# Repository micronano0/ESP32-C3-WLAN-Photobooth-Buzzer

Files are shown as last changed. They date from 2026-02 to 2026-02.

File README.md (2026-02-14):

# Buzzer

Der **Buzzer** dient dazu, Bilder auf einer Fotobox auszulösen.  
Getestet mit **Photobooth 4.99** und **dslrBooth**.

---

## Funktionen

- **HTTP-Befehl** an einen Webserver senden  
- **MQTT-String** an einen Broker senden (optional)  

---

## Installation & Inbetriebnahme

1. **Buzzer einschalten** → startet einen **Access Point** (`Buzzer`).
2. Mit dem Handy verbinden und die **Weboberfläche** öffnen.
3. WLAN auswählen, mit dem sich der Buzzer verbinden soll
4. statische IP und Gateway eingeben.
5. HTTP-Befehl für den Webserver eingeben.
6. Optional: MQTT aktivieren und Broker-Adresse angeben.
7. Konfiguration speichern → Buzzer startet neu und verbindet sich automatisch mit dem WLAN.

---

## Statusanzeigen (LED)

| Status | Bedeutung |
|---|---|
| Blaue LED dauerhaft an | Buzzer erfolgreich im WLAN angemeldet |
| Blaue LED blinkt | WLAN-Verbindung fehlgeschlagen → Access Point aktiv |
| Blaue LED leuchtet, nicht blinkt | Buzzer im WLAN, aber z. B. mqtt fehler |
| 1x Piep | http Befehl erfolgreich gesendet |
| 2x Piep | http Befehl erfolglos |

---

## Zugriff auf den Access Point

Wenn Änderungen nötig sind:

1. Buzzer ausschalten  
2. Buzzerknopf gedrückt halten  
3. Buzzer einschalten
4. blaue LED blinkt  
5. Mit dem Handy wieder verbinden → Weboberfläche aufrufen → Konfiguration ändern

---

## Verwendung / Auslösen

Drücke den **roten Knopf**, dann passiert Folgendes:

| Situation | Signal |
|---|---|
| HTTP-Befehl erfolgreich gesendet | 1x Piepton |
| Webserver nicht erreichbar | 2x Piepton |
| MQTT aktiviert & Broker erreichbar | Blaue LED blinkt 1x |
| MQTT aktiviert & Broker nicht erreichbar | Blaue LED leuchtet dauerhaft |

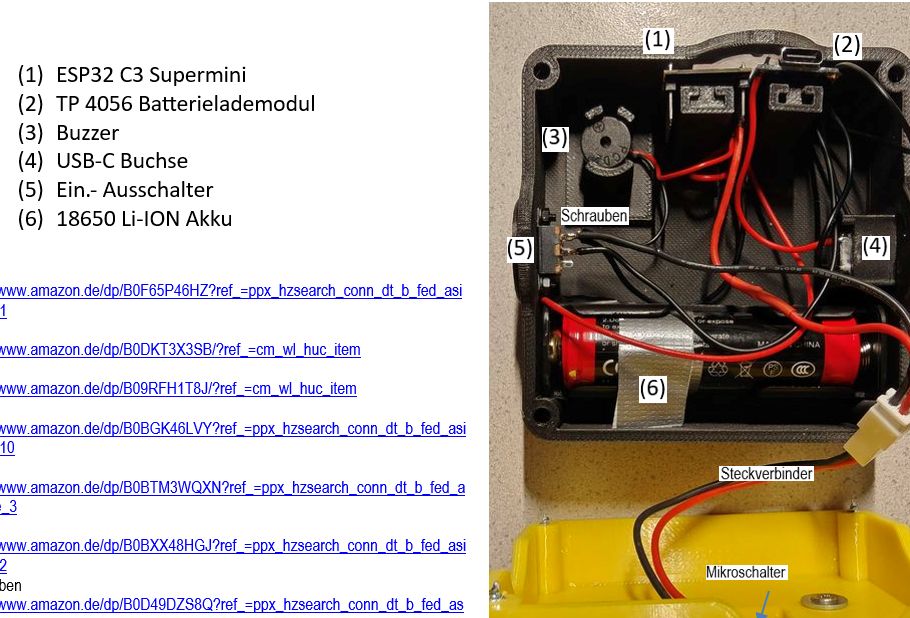
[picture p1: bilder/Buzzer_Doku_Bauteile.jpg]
Buzzer_elektronik_fertig


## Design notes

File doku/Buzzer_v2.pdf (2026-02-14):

### Buzzer

Ich verwende den Buzzer um Bilder auf der Fotobox auszulösen. (getestet wurde Photobooth 4.99 und dslrBooth)

Bei der 1. Inbetriebnahme macht der Buzzer einen AccessPoint auf („Buzzer“) über den man sich mit dem Handy verbinden kann. Über eine Weboberfläche kann man das WLAN auswählen mit dem sich der Buzzer über eine statische IP verbinden soll.

Weiters gibt man den http Befehl ein, welcher an den Webserver gesendet werden soll.

Zusätzlich kann man mqtt aktivieren (wer’s braucht).

Wird die Eingabe gespeichert, dann startet der Buzzer neu und verbindet sich automatisch mit dem eingegebenen WLAN.
Die blaue LED leuchtet durchgehend, wenn sich der Buzzer im WLAN anmelden konnte.
Wurde aber zB eine falsche statische IP vorgegeben, dann ist der Buzzer zwar angemeldet, kann aber nichts machen.

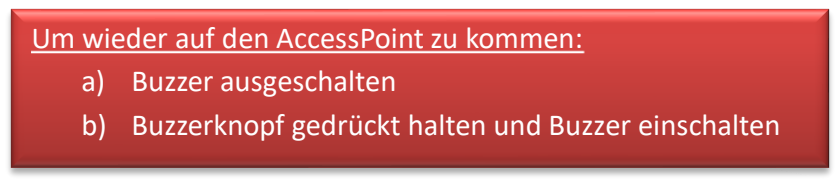
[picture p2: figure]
a) Buzzer ausgeschalten

Handy wieder mit AP verbinden, Webseite aufmachen, Konfiguration ändern.

Konnte sich der Buzzer nicht mit dem WLAN verbinden, dann startet der AccessPoint automatisch, die blau LED blinkt.

Wenn alles richtig konfiguriert ist und man den roten Knopf drückt, dann:
a) Befehl konnte erfolgreich zum Webserver gesendet werden => 1x Piep.
b) Webserver nicht erreichbar => 2x Piep.
c) Mqtt aktiviert und Broker erreichbar => blaue LED blink 1x
d) Mqtt aktiviert und Broker nicht erreichbar => blaue LED bleibt leuchtend (kein blink)

Um wieder auf den AccessPoint zu kommen:

b) Buzzerknopf gedrückt halten und Buzzer einschalten a) einen http Befehl an einen Webserver senden
b) einen mqtt String an einen Broker senden

### Buzzer Menü

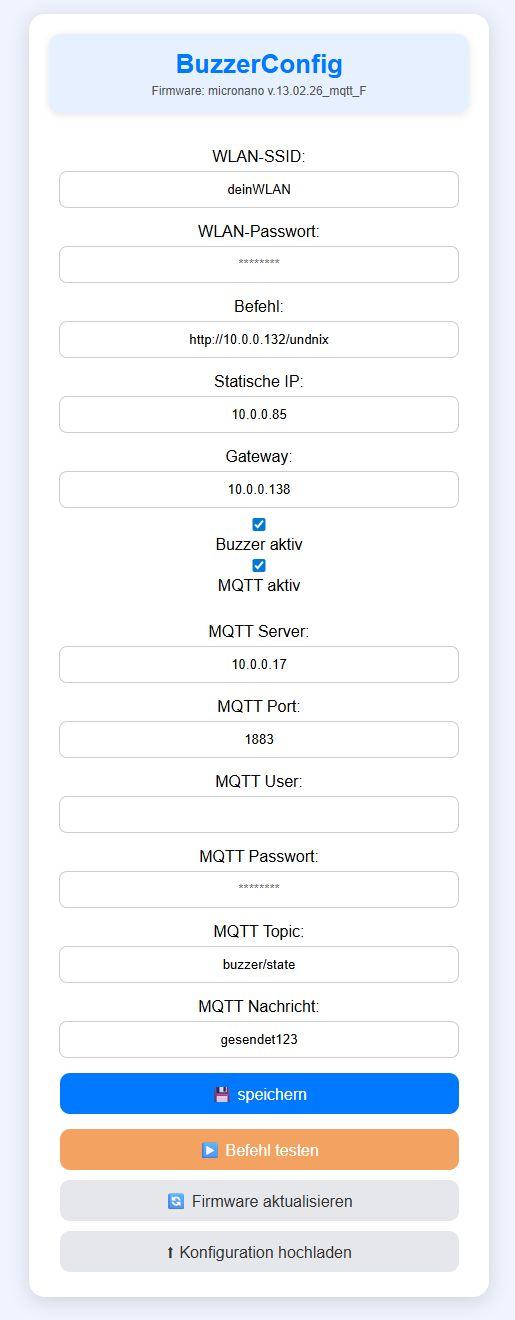
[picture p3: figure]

Firmware aktualisieren: | falls ein Firmware Update zur Verfügung steht
Konfiguration hochladen: | config.json File mit Editor ändern/anpassen und hochladen

### Buzzer Hardware

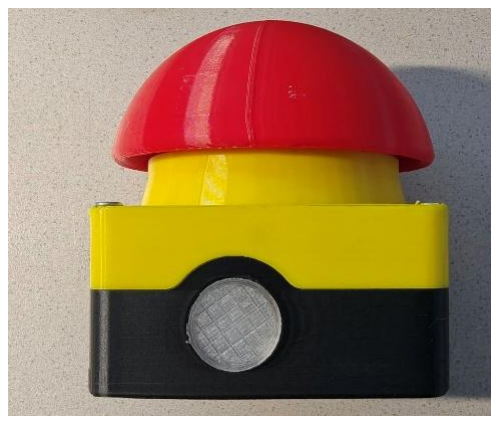
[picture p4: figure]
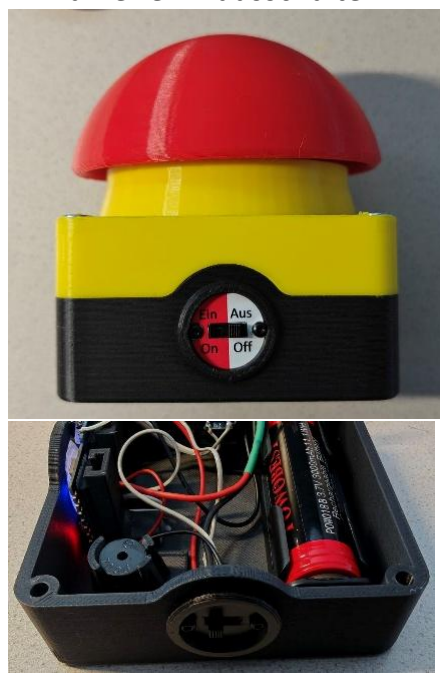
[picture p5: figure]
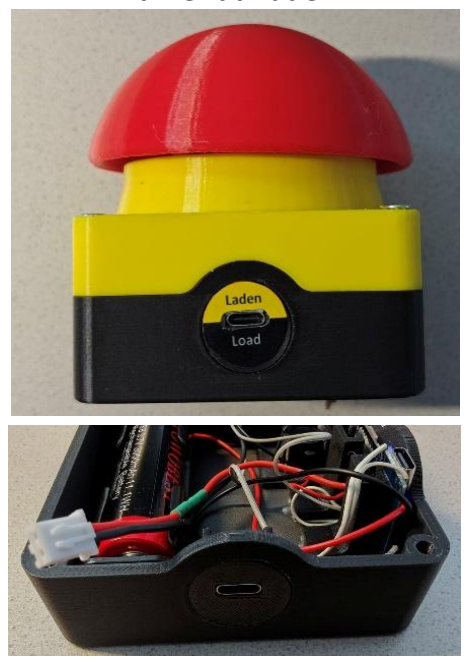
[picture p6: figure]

Buzzer ein.- ausschalten | Buzzer aufladen | Buzzer LED Status

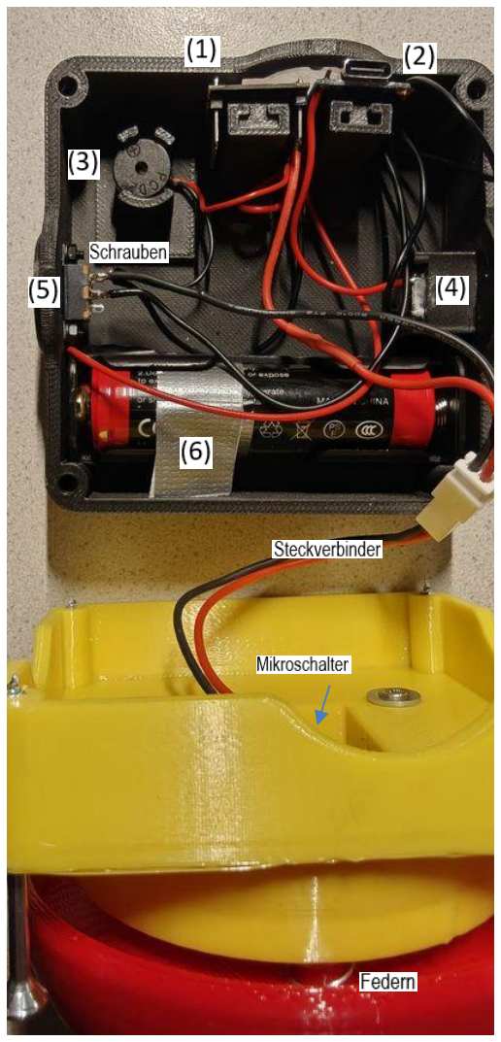
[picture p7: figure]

(1) ESP32 C3 Supermini
(2) TP 4056 Batterielademodul
(3) Buzzer
(4) USB-C Buchse
(5) Ein.- Ausschalter
(6) 18650 Li-ION Akku

(1)
https://www.amazon.de/dp/B0F65P46HZ?ref_=ppx_hzsearch_conn_dt_b_fed_asin_title_1 (https://www.amazon.de/dp/B0F65P46HZ?ref_=ppx_hzsearch_conn_dt_b_fed_asin_title_1)
(2)
https://www.amazon.de/dp/B0DKT3X3SB/?ref_=cm_wl_huc_item
(3)
https://www.amazon.de/dp/B09RFH1T8J/?ref_=cm_wl_huc_item
(4)
https://www.amazon.de/dp/B0BGK46LVY?ref_=ppx_hzsearch_conn_dt_b_fed_asin_title_10 (https://www.amazon.de/dp/B0BGK46LVY?ref_=ppx_hzsearch_conn_dt_b_fed_asin_title_10)
(5)
https://www.amazon.de/dp/B0BTM3WQXN?ref_=ppx_hzsearch_conn_dt_b_fed_asin_title_3 (https://www.amazon.de/dp/B0BTM3WQXN?ref_=ppx_hzsearch_conn_dt_b_fed_asin_title_3)
(6)
https://www.amazon.de/dp/B0BXX48HGJ?ref_=ppx_hzsearch_conn_dt_b_fed_asin_title_2 (https://www.amazon.de/dp/B0BXX48HGJ?ref_=ppx_hzsearch_conn_dt_b_fed_asin_title_2)
Schrauben
https://www.amazon.de/dp/B0D49DZS8Q?ref_=ppx_hzsearch_conn_dt_b_fed_asin_title_1 (https://www.amazon.de/dp/B0D49DZS8Q?ref_=ppx_hzsearch_conn_dt_b_fed_asin_title_1)
Steckverbinder
https://www.amazon.de/dp/B07QMMC4WZ?ref_=ppx_hzsearch_conn_dt_b_fed_asin_title_33 (https://www.amazon.de/dp/B07QMMC4WZ?ref_=ppx_hzsearch_conn_dt_b_fed_asin_title_33)
Mikroschalter
https://www.amazon.de/dp/B07YDFH7H3?ref_=ppx_hzsearch_conn_dt_b_fed_asin_title_1 (https://www.amazon.de/dp/B07YDFH7H3?ref_=ppx_hzsearch_conn_dt_b_fed_asin_title_1)
Federn
https://www.amazon.de/dp/B07WFPPXXX?ref_=ppx_hzsearch_conn_dt_b_fed_asin_title_1 (https://www.amazon.de/dp/B07WFPPXXX?ref_=ppx_hzsearch_conn_dt_b_fed_asin_title_1)

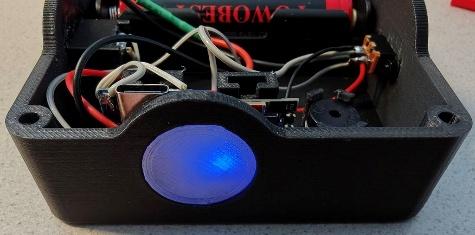
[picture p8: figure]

### MQTT

Windowsprogramme:
a) mosquitto
b) Mqtt Box (AppStore)
1) Terminal als Admin
2) In mosquitto Verzeichnis wechseln: | cd "C:\Program Files\mosquitto"
3) Starte mosquitto im Verzeichnis: | net start mosquitto
4) 2. Terminal check ob 1883 da ist: | netstat -a
5) IP vom PC abfragen: | ipconfig

Einen Testbefehl absenden: .\mosquitto_pub -t buzzer/state -m "ON"

mosquitto.conf:
listener 1883 0.0.0.0
allow_anonymous true
bind_address „IP vom PC“

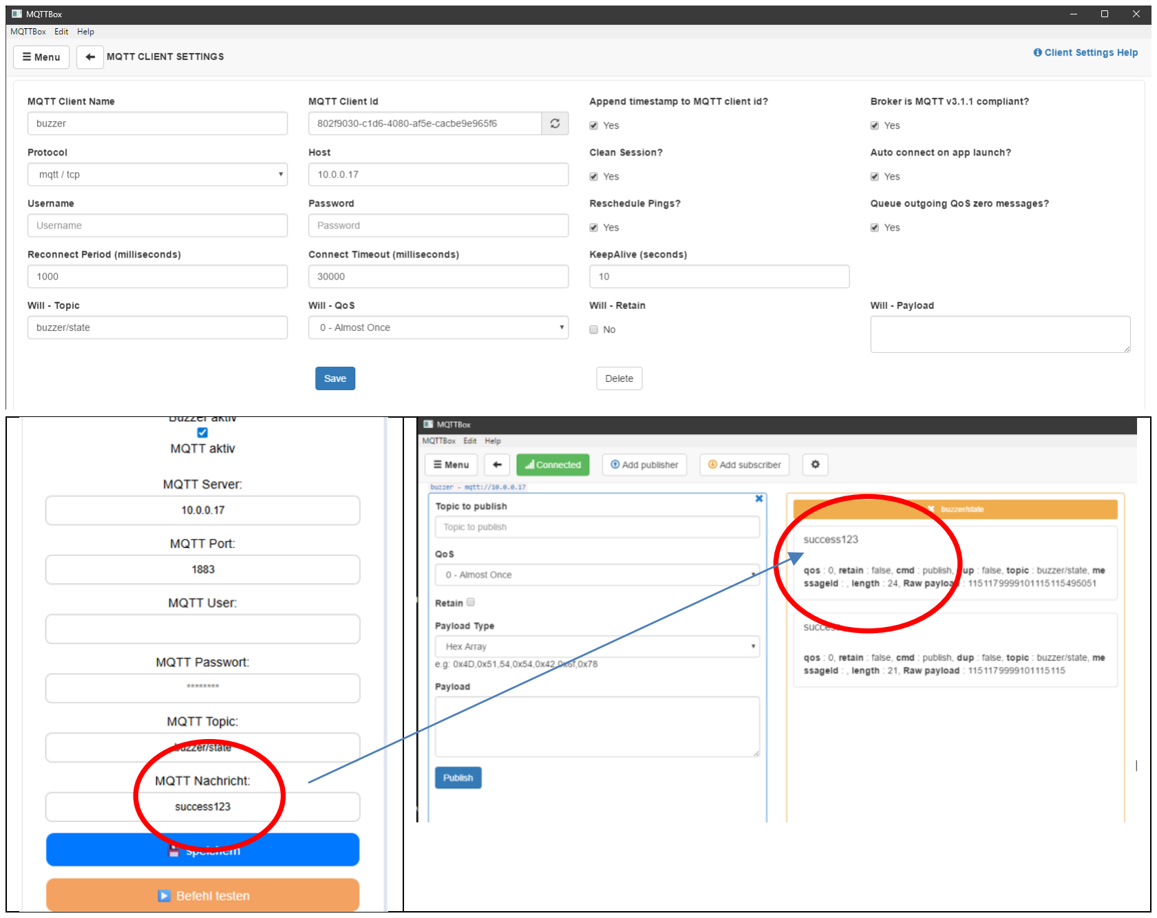
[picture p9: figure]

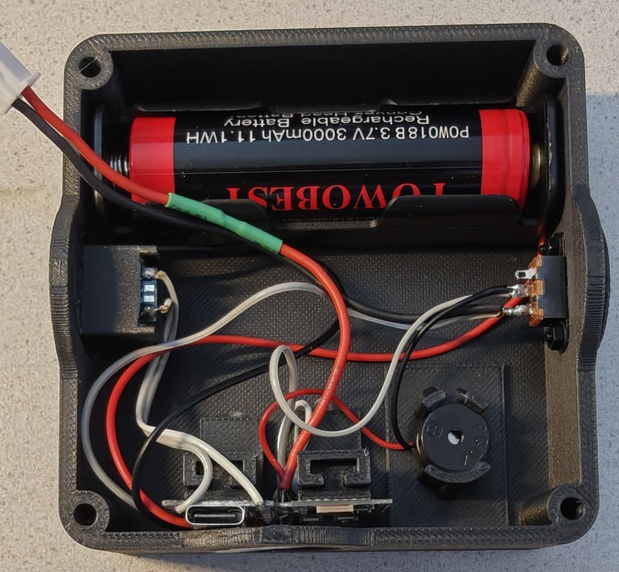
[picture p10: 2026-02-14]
bilder/Buzzer_elektronik.jpg

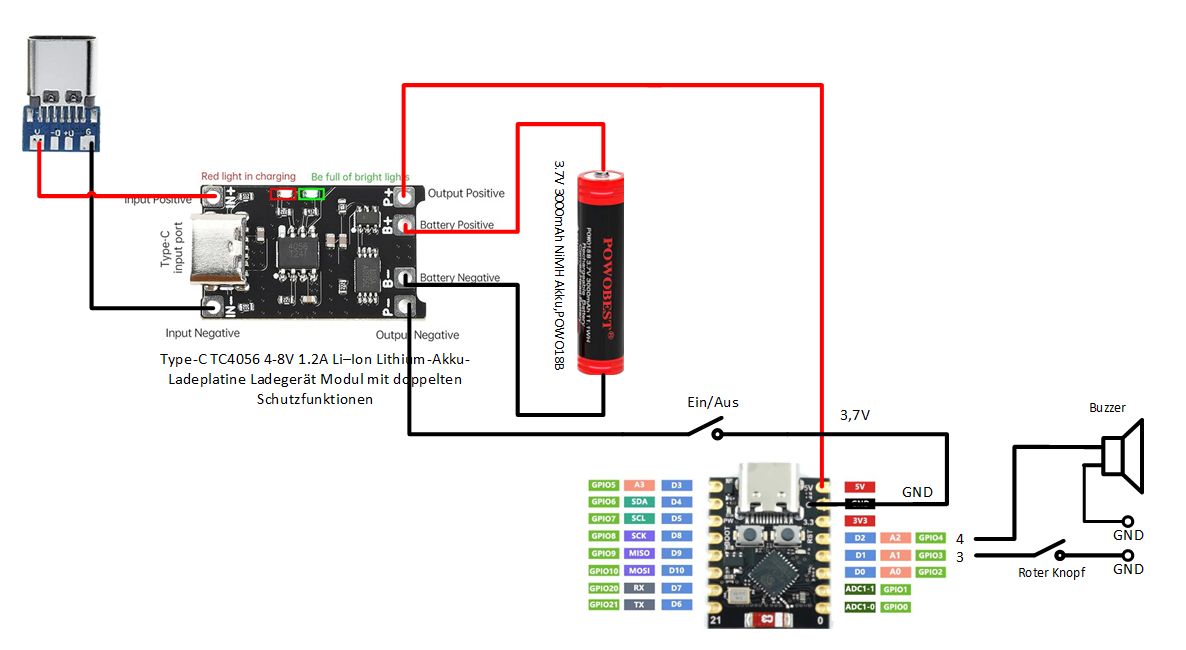
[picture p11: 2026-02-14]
bilder/Buzzer_v2_SchaltPlan.jpg

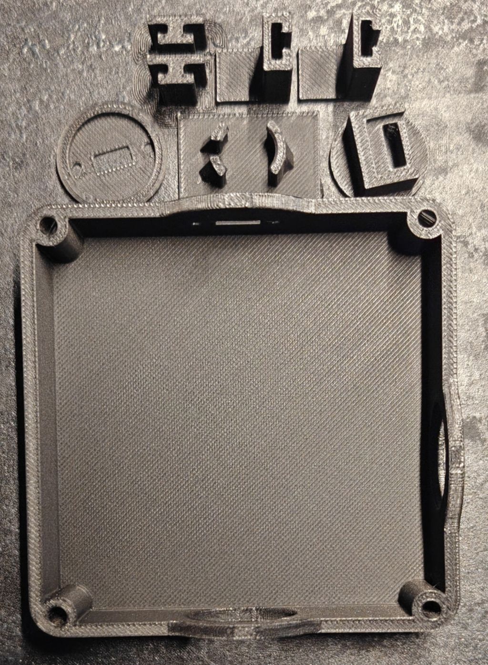
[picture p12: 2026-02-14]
bilder/Buzzer_3D_Druck2.jpg

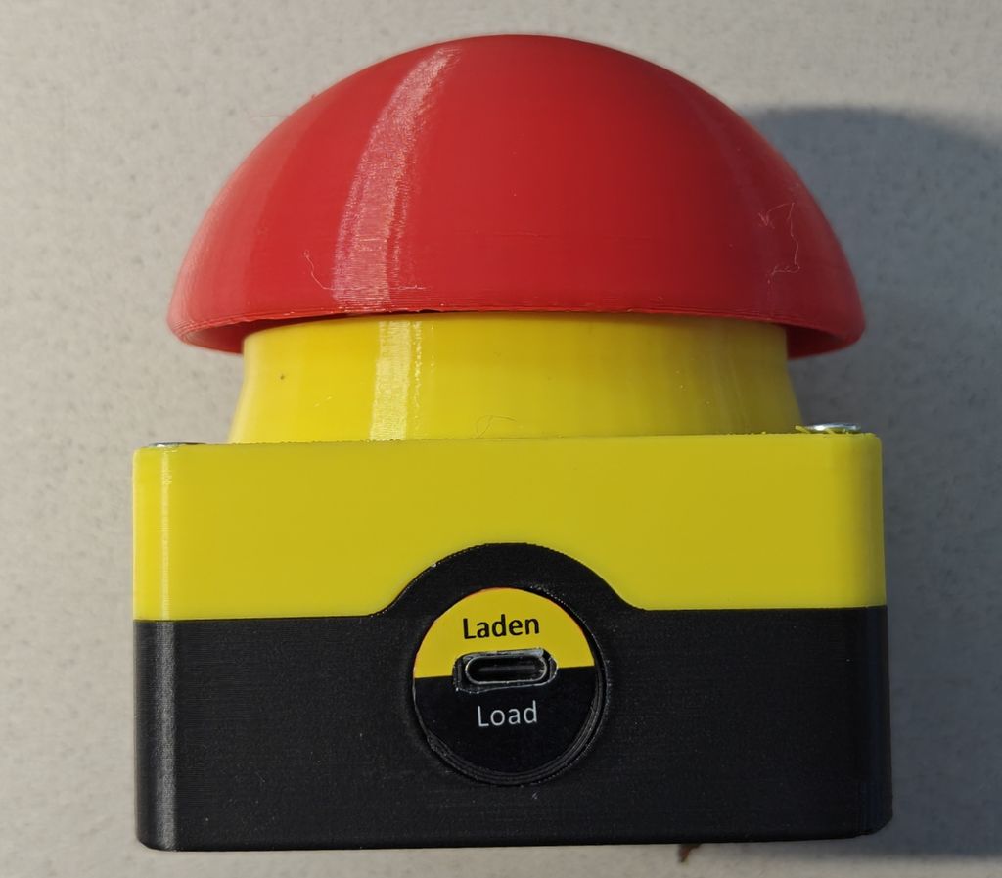
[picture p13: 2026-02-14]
bilder/Buzzer_laden.jpg

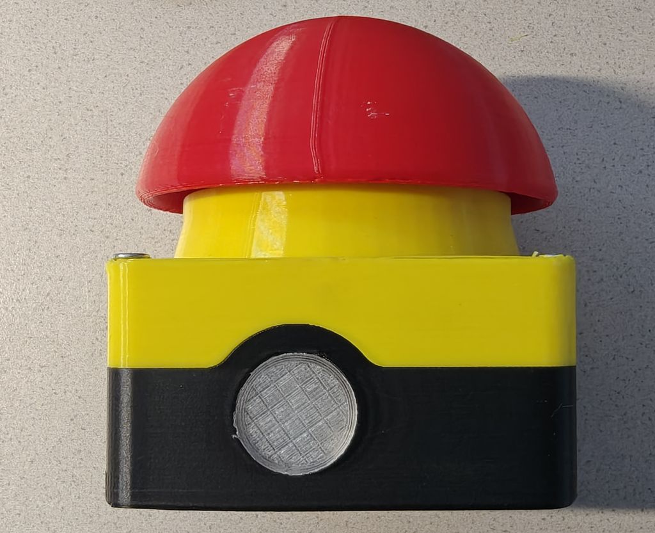
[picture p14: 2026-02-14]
bilder/Buzzer_display.jpg

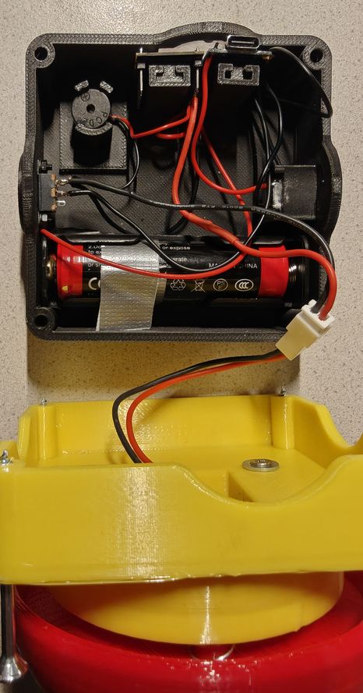
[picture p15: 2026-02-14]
bilder/Buzzer_elektronik_fertig.jpg

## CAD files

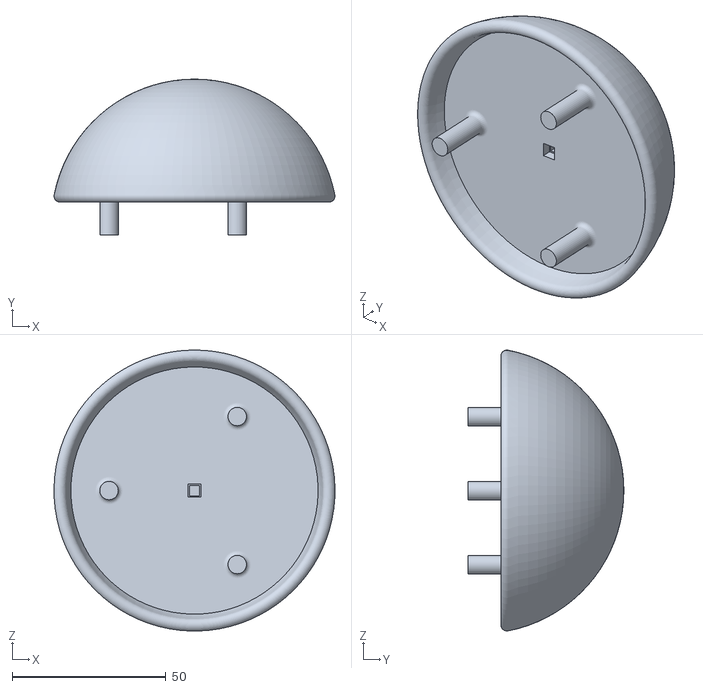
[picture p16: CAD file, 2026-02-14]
stl/BuzzerKnopf.STL
91.4 x 50.6 x 91.3

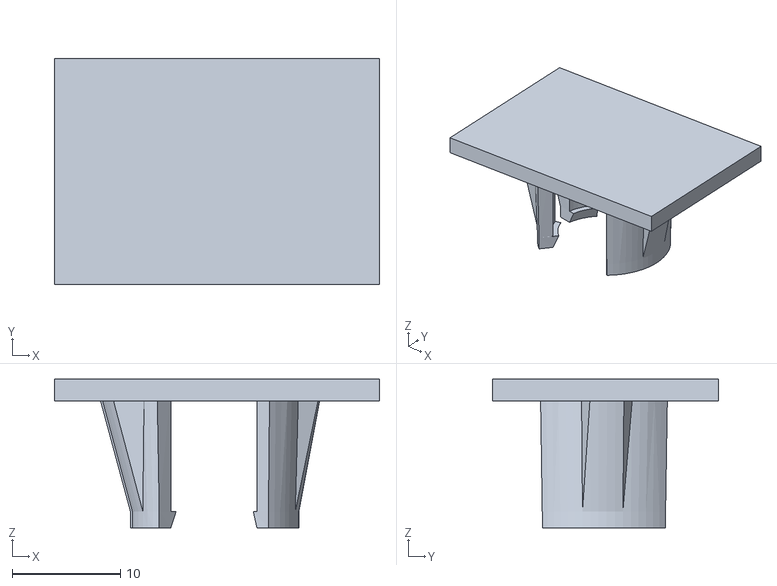
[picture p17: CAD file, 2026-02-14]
stl/buzzer_halterung.stl
30.1 x 21.0 x 13.8

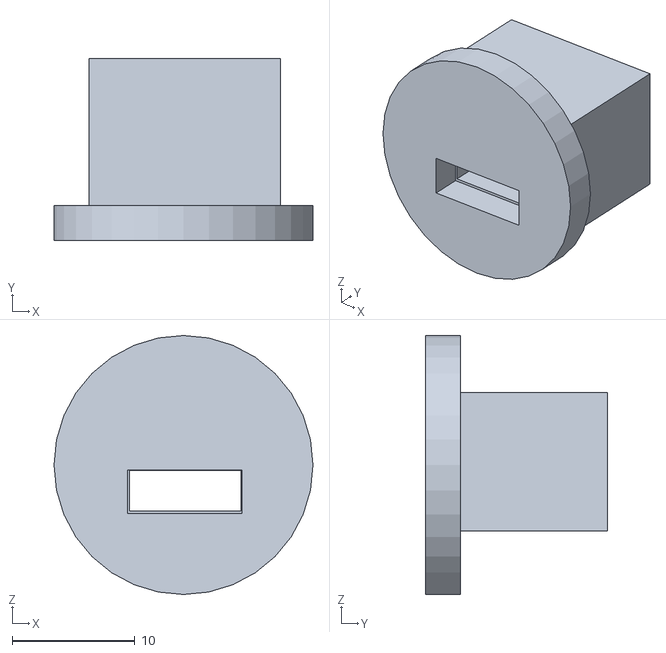
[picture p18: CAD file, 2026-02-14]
stl/usb_c_deckel_2.stl
21.1 x 14.9 x 21.1

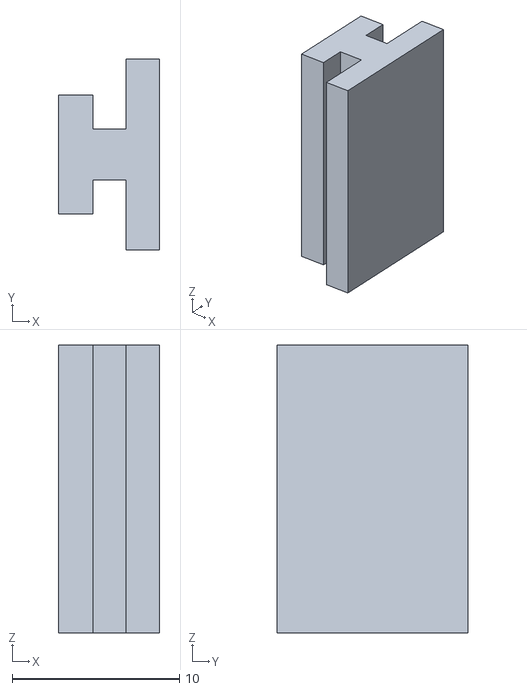
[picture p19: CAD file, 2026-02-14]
stl/Platinenhalter_T1.stl
6.01 x 11.4 x 17.2

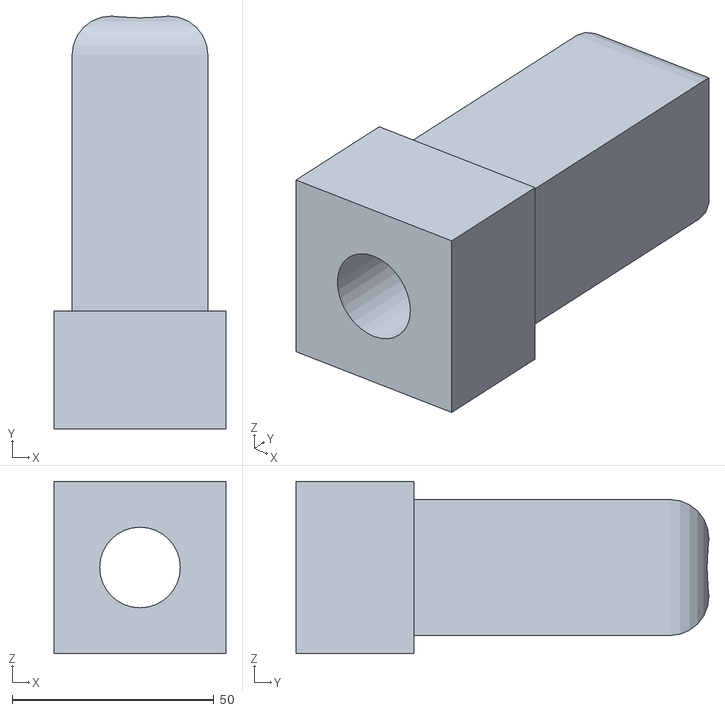
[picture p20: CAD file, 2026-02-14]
stl/buzzer_red_(1)_taster_schraubenhalter.stl
42.7 x 102.4 x 42.8

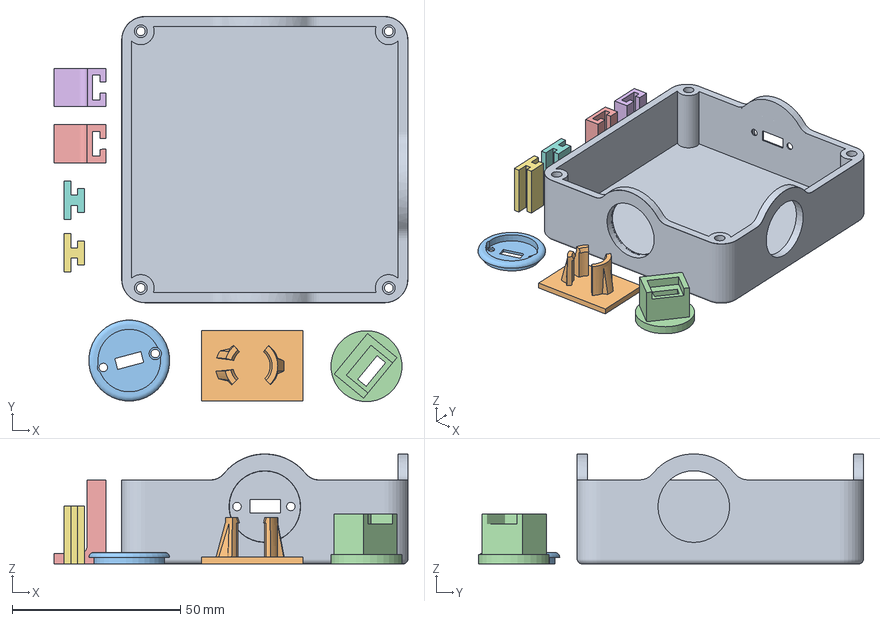
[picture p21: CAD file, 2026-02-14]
stl/gehaeuse.3mf
105.2 x 114.4 x 32.7 mm
BuzzerBoden.STL
buzzer_halterung.stl
schalter_deckel_2.stl
usb_c_deckel_2.stl
Platinenhalter_T2.stl x 2
Platinenhalter_T1.stl x 2

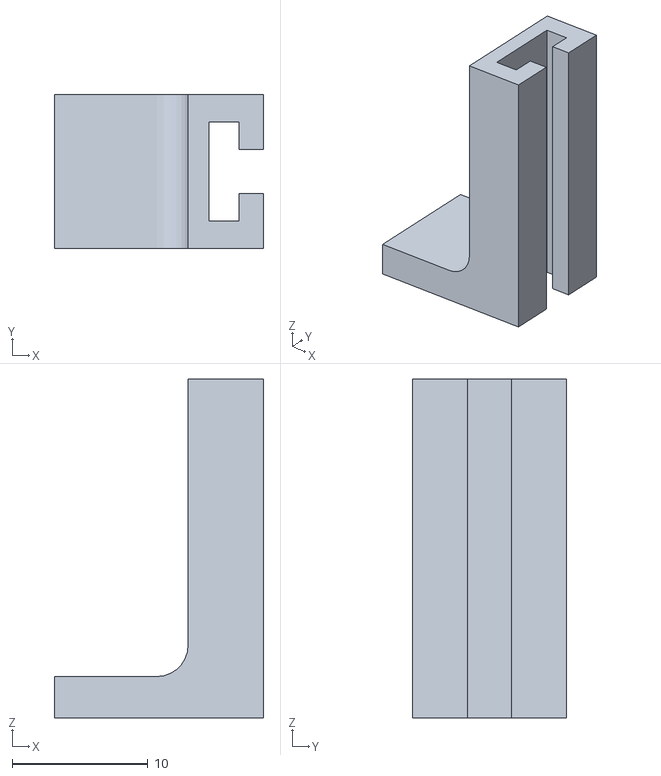
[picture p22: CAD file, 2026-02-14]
stl/Platinenhalter_T2.stl
15.4 x 11.3 x 25.0

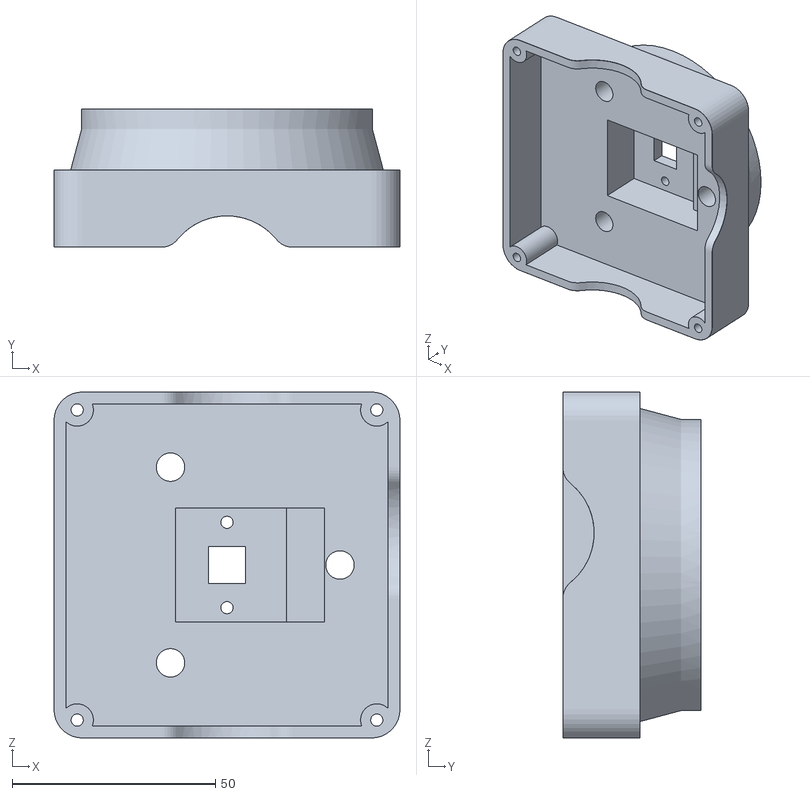
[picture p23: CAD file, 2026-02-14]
stl/BuzzerDeckel.STL
85.1 x 34.0 x 85.1

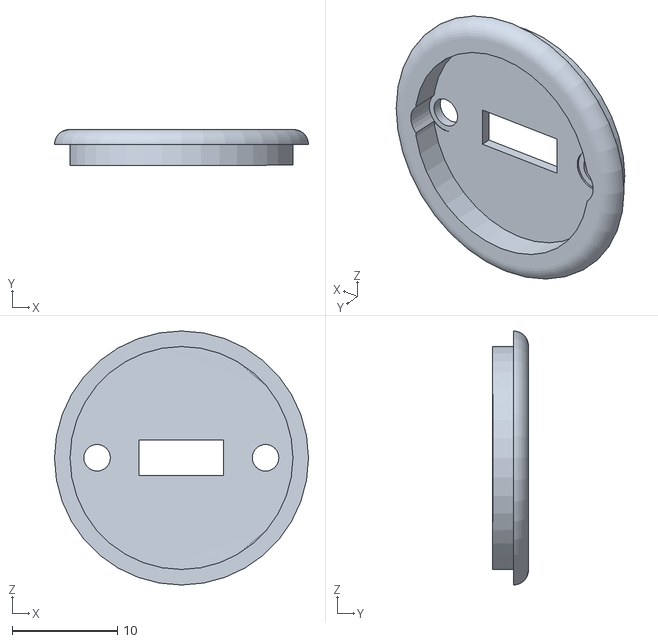
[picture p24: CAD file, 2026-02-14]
stl/schalter_deckel_2.stl
24.1 x 3.42 x 24.1

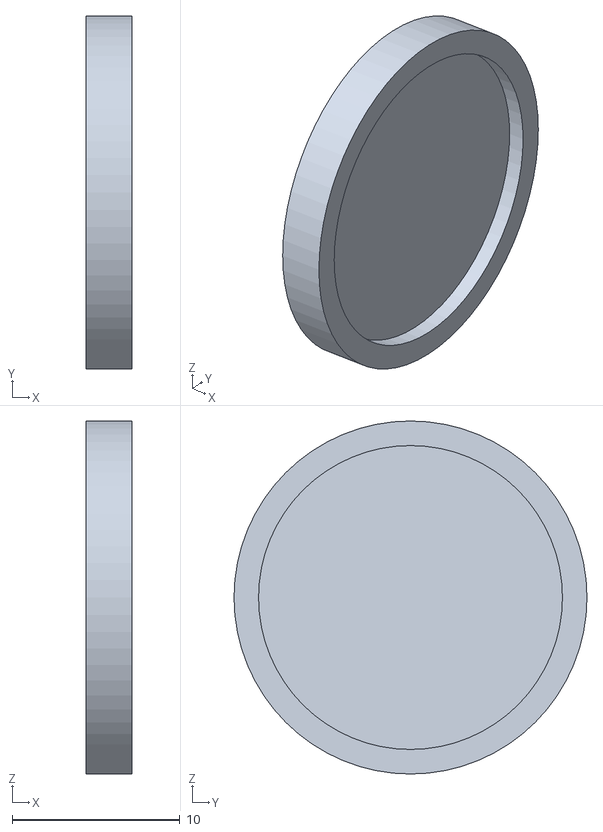
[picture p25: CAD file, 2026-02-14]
stl/sichtfenster_fuer_led.stl
2.72 x 21.0 x 21.0

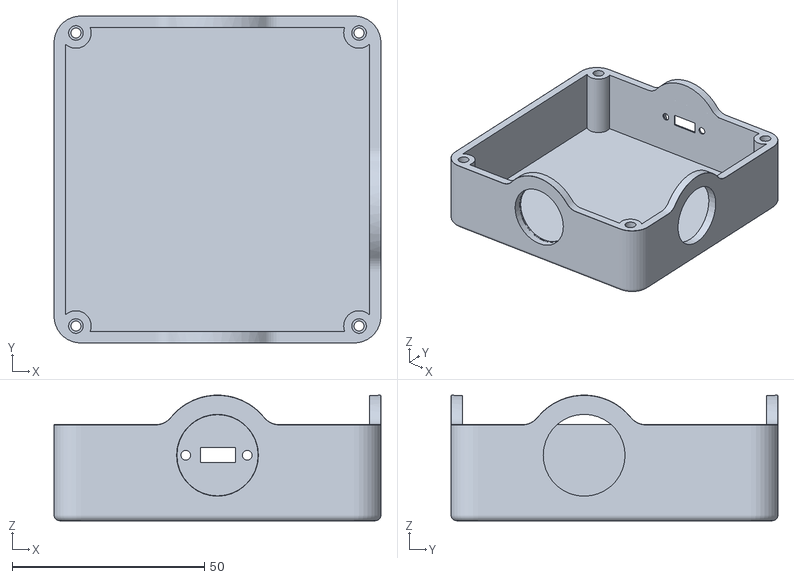
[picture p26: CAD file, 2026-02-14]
stl/BuzzerBoden.STL
85.1 x 85.1 x 32.7

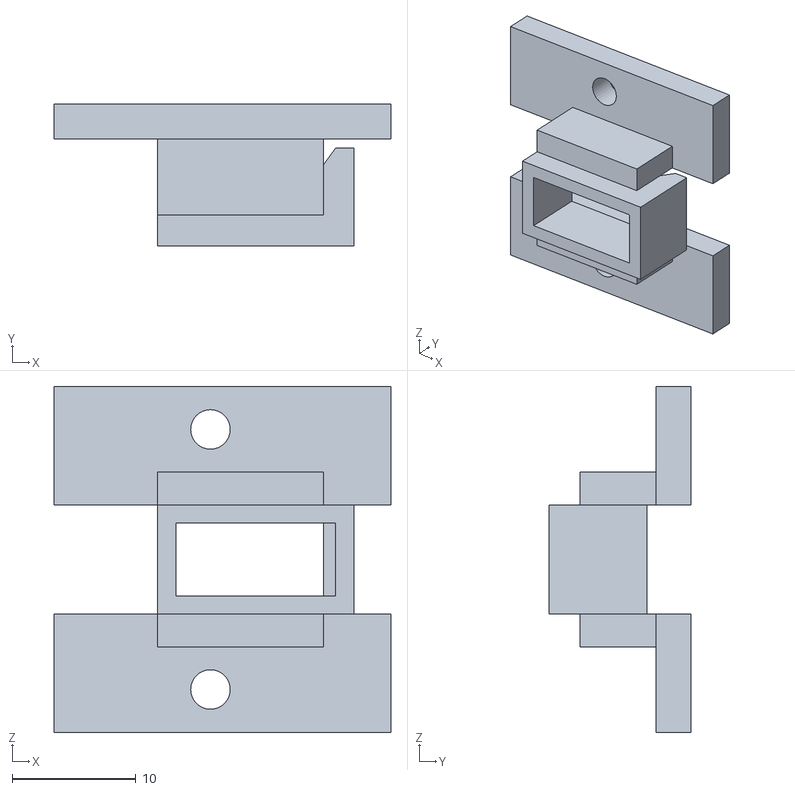
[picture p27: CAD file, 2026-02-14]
stl/buzzer_red_(2)_taster_schalter_gehaeuse.stl
27.2 x 11.5 x 28.0

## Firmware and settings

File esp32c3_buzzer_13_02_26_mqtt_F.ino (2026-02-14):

#include <WiFi.h>
#include <WebServer.h>
#include <HTTPClient.h>
#include <LittleFS.h>
#include <ArduinoJson.h>
#include <HTTPUpdateServer.h>
#include <PubSubClient.h>   

#define BUZZER_PIN 4  // Pin für Soundbuzzer
#define SWITCH_PIN 3  // Pin für Mikroschalter (gegen GND)
//#define LED_PIN LED_BUILTIN     // interne LED
#define LED_PIN 8
#define FIRMWARE_VERSION "micronano v.13.02.26_mqtt_F"

WebServer server(80);
HTTPUpdateServer httpUpdater;
WiFiClient espClient;
PubSubClient mqttClient(espClient);
String clientId = "Buzzer-" + String(random(0xffff), HEX);
bool mqttok = false;

// Für WebUI-Kompatibilität
bool inAPMode = false;

unsigned long lastLEDToggle = 0;
bool ledState = false;
const unsigned long LED_BLINK_INTERVAL = 500;  // 500ms


struct Config {
  String ssid;
  String password;
  String command;
  String localIP;
  String gateway;
  bool buzzerEnabled;
  bool mqttEnabled;
  String mqttServer;
  String mqttUser;
  String mqttPassword;
  int mqttPort;
  String mqttTopic;
  String mqttPayloadSuccess;
};

Config config;

// --- Taster Handling ---
bool lastSwitchState = HIGH;
unsigned long switchLockUntil = 0;
const unsigned long SWITCH_LOCK_TIME = 1000;  // 1s Sperre

// ------------------------------------------------
// ---------------- BEEPER ------------------------
// ------------------------------------------------
void beepAsync(int count, int delayMs = 80) {

  static int remaining = 0;
  static unsigned long lastToggle = 0;
  static bool state = false;
  static int interval = 80;

  if (!config.buzzerEnabled) {
    digitalWrite(BUZZER_PIN, LOW);
    remaining = 0;
    return;
  }

  // 🔥 NEU: nur starten wenn aktuell nichts läuft
  if (count > 0 && remaining == 0) {
    remaining = count * 2;
    interval = delayMs;
    lastToggle = millis();
    state = false;
    digitalWrite(BUZZER_PIN, LOW);
  }

  if (remaining > 0 && millis() - lastToggle >= interval) {
    lastToggle = millis();
    state = !state;
    digitalWrite(BUZZER_PIN, state);
    remaining--;

    if (remaining == 0) {
      digitalWrite(BUZZER_PIN, LOW);
    }
  }
}


void blinkLED(int count, int delayMs = 300) {
  for (int i = 0; i < count; i++) {
    digitalWrite(LED_PIN, LOW);   // AN (blau)
    delay(delayMs);
    digitalWrite(LED_PIN, HIGH);  // AUS
    delay(delayMs);
  }
}

// ------------------------------------------------
// ---------------- MQTT --------------------------
// ------------------------------------------------
bool connectMQTT() {
    if (!config.mqttEnabled) return false;

    // Server setzen
    mqttClient.setServer(config.mqttServer.c_str(), config.mqttPort);

    // Wenn schon verbunden, nichts tun
    if (mqttClient.connected()) return true;

    // --- Serial Debug ---
    Serial.println("=== MQTT Connect Debug ===");
    Serial.print("Server: "); Serial.println(config.mqttServer);
    Serial.print("Port: "); Serial.println(config.mqttPort);
    
    String safePassword = config.mqttPassword.length() ? "***" : "(leer)";
    Serial.print("ClientID: "); Serial.println(clientId);
    Serial.print("User: "); Serial.println(config.mqttUser.length() ? config.mqttUser : "(leer)");
    Serial.print("Passwort: "); Serial.println(safePassword);
    Serial.println("==========================");

    // Verbindung versuchen
    Serial.print("MQTT verbinde... ");
    if (mqttClient.connect(clientId.c_str(), config.mqttUser.c_str(), config.mqttPassword.c_str())) {
        Serial.println("OK");
        return true;
    } else {
        Serial.print("Fehler, mqttClient.state() = ");
        Serial.println(mqttClient.state());
        return false;
    }
}


void sendMQTTMessage(String payload) {
  if (!config.mqttEnabled) return;

  if (!mqttClient.connected()) {
    if (!connectMQTT()) return;
  }

  mqttClient.publish(config.mqttTopic.c_str(), payload.c_str());
}


// ------------------------------------------------
// ---------------- CONFIG ------------------------
// ------------------------------------------------
void saveConfig() {
  DynamicJsonDocument doc(1024);

  doc["ssid"] = config.ssid;
  doc["password"] = config.password;
  doc["command"] = config.command;
  doc["localIP"] = config.localIP;
  doc["gateway"] = config.gateway;
  doc["buzzerEnabled"] = config.buzzerEnabled;
  doc["mqttEnabled"] = config.mqttEnabled;
  doc["mqttServer"] = config.mqttServer;
  doc["mqttUser"] = config.mqttUser;
  doc["mqttPassword"] = config.mqttPassword;
  doc["mqttPort"] = config.mqttPort;
  doc["mqttTopic"] = config.mqttTopic;
  doc["mqttPayloadSuccess"] = config.mqttPayloadSuccess;
   File file = LittleFS.open("/config.json", "w");
  serializeJson(doc, file);
  file.close();
}

bool loadConfig() {
  if (!LittleFS.exists("/config.json")) return false;

  File file = LittleFS.open("/config.json", "r");
  DynamicJsonDocument doc(1024);

  if (deserializeJson(doc, file)) {
    file.close();
    return false;
  }

  config.ssid = doc["ssid"] | "";
  config.password = doc["password"] | "";
  config.command = doc["command"] | "";
  config.localIP = doc["localIP"] | "";
  config.gateway = doc["gateway"] | "";
  config.buzzerEnabled = doc["buzzerEnabled"] | true;
  config.mqttEnabled = doc["mqttEnabled"] | false;
  config.mqttServer = doc["mqttServer"] | "";
  config.mqttUser = doc["mqttUser"] | "";
  config.mqttPassword = doc["mqttPassword"] | "";
  config.mqttPort = doc["mqttPort"] | 1883;
  config.mqttTopic = doc["mqttTopic"] | "";
  config.mqttPayloadSuccess = doc["mqttPayloadSuccess"] | "success";
  file.close();
  return true;
}

// ---------- NEU: IP Erreichbarkeit prüfen (einfach HTTP Connect) ----------
bool isIPReachable(String url) {
  HTTPClient http;
  http.setConnectTimeout(500);
  if (!http.begin(espClient, url)) return false;
  int code = http.GET();
  http.end();
  return (code > 0);
}

// ---------- WLAN Logik ----------
bool connectWiFi() {
  if (config.ssid.length() == 0) return false;

  WiFi.mode(WIFI_STA);

  // Statische IP nur setzen, wenn beide Werte vorhanden
  if (config.localIP.length() > 0 && config.gateway.length() > 0) {
    IPAddress local, gw, sn(255, 255, 255, 0);
    if (local.fromString(config.localIP) && gw.fromString(config.gateway)) {
      WiFi.config(local, gw, sn);
      Serial.println("Statische IP gesetzt: " + local.toString());
    } else {
      Serial.println("Ungültige IP/Gateway, DHCP wird verwendet");
    }
  } else {
    Serial.println("DHCP wird verwendet");
  }

  WiFi.begin(config.ssid.c_str(), config.password.c_str());
  Serial.print("Verbinde mit WLAN");

  unsigned long start = millis();
  while (WiFi.status() != WL_CONNECTED && millis() - start < 15000) {  // 15s Timeout
    Serial.print(".");
    delay(100);
  }
  Serial.println();

  if (WiFi.status() != WL_CONNECTED) {
    Serial.println("❌ WLAN Verbindung fehlgeschlagen");
    return false;
  }

  Serial.println("✅ WLAN verbunden, IP: " + WiFi.localIP().toString());
  return true;
}

// ------------------------------------------------
// ---------------- HTTP --------------------------
// ------------------------------------------------
bool sendHttp() {

  HTTPClient http;
  http.setConnectTimeout(500);

  if (!http.begin(espClient, config.command)) return false;

  int httpCode = http.GET();
  http.end();

  if (httpCode == 200) {
    beepAsync(1);
    return true;
  } else {
    beepAsync(2);
    return false;
  }
}

bool sendMqtt() {
  if (!config.mqttEnabled) return false;

  if (!mqttClient.connected()) {
    if (!connectMQTT()) {
      beepAsync(2);   // Fehler
      return false;
    }
  }

  if (mqttClient.publish(config.mqttTopic.c_str(),
                         config.mqttPayloadSuccess.c_str())) {
    beepAsync(1);     // Erfolg
    return true;
  } else {
    beepAsync(2);     // Fehler
    return false;
  }
}


void handleSave() {
  config.ssid = server.arg("ssid");

  if (server.arg("password").length() > 0)
    config.password = server.arg("password");

  config.localIP = server.arg("localIP");   // neu
  config.gateway = server.arg("gateway");   // neu
  config.command = server.arg("command");

  config.buzzerEnabled = server.hasArg("buzzerEnabled");
  config.mqttEnabled = server.hasArg("mqttEnabled");

  config.mqttServer = server.arg("mqttServer");
  config.mqttUser = server.arg("mqttUser");

  if (server.arg("mqttPassword").length() > 0)
    config.mqttPassword = server.arg("mqttPassword");

  config.mqttPort = server.arg("mqttPort").toInt();
  config.mqttTopic = server.arg("mqttTopic");
  config.mqttPayloadSuccess = server.arg("mqttPayloadSuccess");

  saveConfig();

  if (!config.mqttEnabled) {
    if (mqttClient.connected()) {
      mqttClient.disconnect();
      Serial.println("MQTT deaktiviert – Verbindung getrennt");
    }
  }

  server.send(200,"text/html","Gespeichert. Neustart...");
  delay(1500);
  ESP.restart();
}


// ---------------- WebUI -----------------
void handleRoot() {
  String html = "<!DOCTYPE html><html lang='de'><head>"
                "<meta charset='UTF-8'>"
                "<meta name='viewport' content='width=device-width, initial-scale=1'>"
                "<title>BuzzerConfig</title>"
                "<style>"
                "body{font-family:sans-serif;background:#f0f4ff;text-align:center;padding:10px;margin:0;}"
                ".card{max-width:420px;width:95%;margin:20px auto;background:white;padding:20px;"
                "border-radius:16px;box-shadow:0 4px 20px rgba(0,0,0,0.15);}"
                ".header-block{background:#e6f0ff;padding:15px 20px;margin-bottom:15px;"
                "border-radius:12px;box-shadow:0 2px 8px rgba(0,0,0,0.1); text-align:center;}"
                ".header-block h2, .header-block p{margin:0;}"
                ".header-block h2{font-size:26px;color:#0078ff;}"
                ".header-block p{margin-top:4px;font-size:12px;color:#555;}"
                "form{display:flex;flex-direction:column;align-items:center;}"
                "form label{width:100%;text-align:center;margin-top:10px;font-weight:500;}"
                "form input{width:90%;padding:10px;margin:5px 0;border-radius:8px;border:1px solid #ccc; text-align:center;}"
                "button{border:none;padding:10px 0;border-radius:10px;font-size:16px;width:95%;margin:10px 0;cursor:pointer;transition:0.2s;}"
                "button.primary{background:#0078ff;color:white;}"
                "button.orange{background:#f4a261;color:white;}"
                "button.gray{background:#e5e7eb;color:#333;}"
                "button.red{background:#e53935;color:white;}"
                "button:hover{opacity:0.9;}"
                "a button{width:95%;margin:5px 0;}"
                "@media(max-width:480px){.header-block h2{font-size:22px;} form input{width:95%;} button{width:100%;}}"
                "</style></head><body>"
                "<div class='card'>"
                "<div class='header-block'>"
                "<h2>BuzzerConfig</h2>"
                "<p>Firmware: " FIRMWARE_VERSION "</p>"
                "</div>"
                "<div style='height:10px;'></div>"
                "<form action='/save' method='POST'>"
                "<label>WLAN-SSID:</label><input name='ssid' value='" + config.ssid + "'>"
                "<label>WLAN-Passwort:</label><input type='password' name='password' placeholder='********'>"
                "<label>Befehl:</label><input name='command' value='" + config.command + "'>"
                "<label>Statische IP:</label><input name='localIP' value='" + (config.localIP.length() ? config.localIP : "") + "' placeholder='192.168.1.50'>"
                "<label>Gateway:</label><input name='gateway' value='" + (config.gateway.length() ? config.gateway : "") + "' placeholder='192.168.1.1'>"
                "<input type='checkbox' name='buzzerEnabled' " + String(config.buzzerEnabled ? "checked" : "") + "> Buzzer aktiv"
                "<input type='checkbox' name='mqttEnabled' " + String(config.mqttEnabled ? "checked" : "") + "> MQTT aktiv<br><br>"
                "<label>MQTT Server:</label><input name='mqttServer' value='" + config.mqttServer + "'>"
                "<label>MQTT Port:</label><input name='mqttPort' value='" + String(config.mqttPort) + "'>"
                "<label>MQTT User:</label><input name='mqttUser' value='" + config.mqttUser + "'>"
                "<label>MQTT Passwort:</label><input type='password' name='mqttPassword' placeholder='********'>"
                "<label>MQTT Topic:</label><input name='mqttTopic' value='" + config.mqttTopic + "'>"
                "<label>MQTT Nachricht:</label><input name='mqttPayloadSuccess' value='" + config.mqttPayloadSuccess + "'>"
                "<button type='submit' class='primary'>💾 speichern</button>"
                "</form>"
                "<a href='/trigger'><button class='orange'>▶️ Befehl testen</button></a>"
                "<a href='/update'><button class='gray'>🔄 Firmware aktualisieren</button></a>"
                "<a href='/upload'><button class='gray'>⬆ Konfiguration hochladen</button></a>"
                "</div></body></html>";

  // Einfaches server.send(), kein sendContent, kein CONTENT_LENGTH_UNKNOWN
  server.send(200, "text/html", html);
}

// ----------------- Upload Handler ----------------
void handleFileUpload() {
    HTTPUpload& upload = server.upload();
    if (upload.status == UPLOAD_FILE_START) {
        Serial.print("Upload Start: "); Serial.println(upload.filename);
        // Nur config.json zulassen
        if(upload.filename != "config.json"){
            Serial.println("Nur config.json erlaubt!");
            return;
        }
        File fsUploadFile = LittleFS.open("/config.json", "w");
        if(fsUploadFile) fsUploadFile.close();
    } else if (upload.status == UPLOAD_FILE_WRITE) {
        File fsUploadFile = LittleFS.open("/config.json", "a");
        if (fsUploadFile) {
            fsUploadFile.write(upload.buf, upload.currentSize);
            fsUploadFile.close();
        }
    } else if (upload.status == UPLOAD_FILE_END) {
        Serial.print("Upload fertig: "); Serial.println(upload.filename);
        loadConfig(); // Config direkt nach Upload laden
    }
}

void handleTrigger() {
 
  bool httpOK = sendHttp();
  if (!httpOK) {
    beepAsync(2);
  }


  if (mqttok && config.mqttEnabled) {
    bool oldLedState = digitalRead(LED_PIN);
    bool mqttOK = sendMqtt();
    if (mqttOK) {
      blinkLED(1);   // Erfolg → 1x
    } else {
      //blinkLED(2);   // Fehler → 2x
    }
    digitalWrite(LED_PIN, oldLedState);
  }



  server.sendHeader("Location", "/");
  server.send(303);
}




// ---------------- WebUI Setup -----------------
void setupWebUI() {
  server.on("/", handleRoot);
  server.on("/save", handleSave);

    // ---------------- Upload Form (GET) ----------------
    server.on("/upload", HTTP_GET, []() {
        server.send(200, "text/html",
            "<h3>config.json Upload</h3>"
            "<form method='POST' action='/upload' enctype='multipart/form-data'>"
            "<input type='file' name='config'>"
            "<input type='submit' value='Hochladen'>"
            "</form>"
        );
    });

// ---------------- Upload Verarbeiten (POST) ----------------
server.on("/upload", HTTP_POST, []() {
    // Nach Abschluss des Uploads entscheiden wir, ob Neustart nötig ist
    if (LittleFS.exists("/config.json")) {  // Beispiel: config hochgeladen
        // Optional: kurze Rückmeldung an Browser vor Neustart
        server.send(200, "text/html", "<html><body>Konfiguration gespeichert. Neustart...</body></html>");
        delay(500);           // kleine Pause, damit Browser Response bekommt
        ESP.restart();        // Neustart initiieren
    } else {
        // Normale Weiterleitung auf Startseite
        server.sendHeader("Location", "/");
        server.send(303);
    }
}, handleFileUpload);

  server.on("/trigger", handleTrigger);

  httpUpdater.setup(&server, "/update");
  server.begin();
  Serial.println("Webserver läuft!");
}


void updateWiFiLED() {
  bool wifiConnected =
    (WiFi.getMode() == WIFI_MODE_STA) && (WiFi.status() == WL_CONNECTED);

  if (wifiConnected) {
    // Dauerhaft AN (blau)
    digitalWrite(LED_PIN, LOW);
  } else {
    // Blinken wenn nicht verbunden
    if (millis() - lastLEDToggle >= 500) {
      lastLEDToggle = millis();
      ledState = !ledState;
      digitalWrite(LED_PIN, ledState ? LOW : HIGH);
    }
  }
}


// ---------- Setup ----------
void setup() {
    Serial.begin(9600);

    // --- Pins initialisieren ---
    pinMode(BUZZER_PIN, OUTPUT);
    digitalWrite(BUZZER_PIN, LOW);

    pinMode(SWITCH_PIN, INPUT_PULLUP);

    pinMode(LED_PIN, OUTPUT);
    digitalWrite(LED_PIN, HIGH);

    // --- LittleFS mounten ---
    if (!LittleFS.begin(true)) {
        Serial.println("❌ LittleFS Fehler");
        return;
    }

    // --- Config laden ---
    loadConfig();

    // --- Taster prüfen: AP erzwingen? ---
    bool forceAP = digitalRead(SWITCH_PIN) == LOW;

    // --- WLAN verbinden ---
    bool wifiOK = !forceAP && connectWiFi();

    if (!wifiOK || forceAP) {
        // AP-Modus starten
        Serial.println("➡️ AP-Modus aktiv");
        WiFi.mode(WIFI_AP);
        WiFi.softAP("Buzzer", "12345678");
        inAPMode = true;
    } else {
        inAPMode = false;
        Serial.println("✅ WLAN verbunden, IP: " + WiFi.localIP().toString());

        // --- MQTT initialisieren ---
        mqttClient.setServer(config.mqttServer.c_str(), config.mqttPort);
        mqttClient.setSocketTimeout(2);  // 2 Sekunden
        mqttClient.setKeepAlive(10);     // optional

        // --- MQTT-Broker testen ---
        WiFiClient test;
        Serial.print("Teste MQTT-Broker...");
        if (test.connect(config.mqttServer.c_str(), config.mqttPort)) {
            mqttok = true;
            //blinkLED(1);   // Erfolg → 1x
            Serial.println("OK, Broker erreichbar");
        } else {
            mqttok = false;
            //blinkLED(2);   // Fehler → 2x
            Serial.println("NICHT erreichbar");
        }
    }

    // --- WebUI starten ---
    setupWebUI();
}


// ---------- Loop ----------
void loop() {
  server.handleClient();
  // --- WLAN-LEDs aktualisieren ---
  updateWiFiLED();

  beepAsync(0);

  if (config.mqttEnabled)
    mqttClient.loop();

  // --- Taster Logik ---
  bool currentState = digitalRead(SWITCH_PIN);

  if (lastSwitchState == HIGH && currentState == LOW) {
    if (millis() > switchLockUntil && WiFi.status() == WL_CONNECTED) {
      switchLockUntil = millis() + SWITCH_LOCK_TIME;
      handleTrigger();
    }
  }
//digitalWrite(BUZZER_PIN, LOW);

  lastSwitchState = currentState;
}
